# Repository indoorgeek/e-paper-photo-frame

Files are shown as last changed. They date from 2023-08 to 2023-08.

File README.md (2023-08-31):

# E-Paper Photo Frame
 <br/>
Someone has rightly said that "Memories are special moments that tell our story!". I wanted to build something which can bring back the old memories from my favorite places. I had recently got my hands on an e-paper display and such displays mimic the appearance of ink on a good old paper. Perfect! I made a photo frame using a PCB showing my favorite places on a map. Touching any one of the location pads displays an image from that place on the e-paper display.
# The Plan

The brains of the project is an ESP32 microcontroller. I chose this microcontroller mainly for its touch sensing capability on 10 GPIO pins.

The plan is to display a few of my favorite places on a map on the PCB's silkscreen layer. The copper touchpads would then be placed pointing at the locations. The PCB will have a cutout in the middle for the e-paper display i.e. the PCB itself will be a part of the frame. PCB will have a black solder mask along with an ENIG finish. White silkscreen on a black background and gold-plated touchpads. Sweet!

Next, I have to select my favorite images from each location, prepare them for the e-paper display in bitmap (BMP) format, and store them on an SD card.

The next step is to write a code that detects touch and displays an image from that place.

Finally, the last step is to design and 3D print a body to hold all the electronics.
# PCB Design
<p float="center">
  
   
</p>
The first step is to create a silkscreen layer showing the layout of the maps. I wanted only the roads to be visible on the map. For that, I used [this](https://mapstyle.withgoogle.com/) amazing tool by Google Maps. It allows us to edit a lot of things visible on the map. I removed all the buildings and labels and set the color of the road to black and the rest of everything to white. I then grabbed a screenshot and converted the image into PNG showing only the roads and some other stuff that I wanted to be on the silkscreen layer. Finally, after converting the PNG to DXF (which shows just the outline), I imported it onto the silkscreen layer. Pretty sure that there's an efficient way of doing it.

Next, I designed the copper touchpads (as a PCB footprint) to look like the map 'location' symbol. I then placed the pads on the front copper layer at appropriate locations. When it comes to capacitive touchpads, there are few rules which you need to follow. You can read a complete guide on touchpad design [here](https://github.com/ESP32DE/esp-iot-solution-1/blob/master/documents/touch_pad_solution/touch_sensor_design_en.md). That's a lot but this is the minimum I followed and it worked:
- Trace length should not exceed 300mm
- Trace width < 0.18mm (7 mil)
- The angle between two connecting trace segments should not be less than 90 degrees
- No ground plane directly behind (i.e. on bottom layer) or beside the pad. The guide tells us to add a 'hatched' ground plane but that would have affected the appearance. Anyway, it worked for me.
- No ground plane besides the traces
- Pads and traces on the separate layers
- Make sure that there is no ground pour under ESP32's antennae.

I finally exported the gerber files and sent them to [JLCPCB](https://jlcpcb.com/) for fabrication.

# Time for Code
## Preparing Images
Refer this amazing [guide](https://learn.adafruit.com/preparing-graphics-for-e-ink-displays/convert-with-photoshop) by Adafruit to convert images into proper readable format using Photoshop.<br/>
Before you copy your images on the SD card, make sure that the image file names are in UPPERCASE. For example, PIC1.BMP.
## Code
The code basically performs the following functions:
- It checks if a touch is detected using touch interrupts and displays an image associated with that touchpad
- If the time elapsed is > 1hr, it displays a joke/quote from the internet (for fun!)<br/>

I am pulling jokes from [JokeAPI](https://official-joke-api.appspot.com/) and quotes from [Quotable](https://github.com/lukePeavey/quotable). The data is received in JSON format which is deserialized to get the required jokes/quotes.

I have used the following libraries in the code:
- 4.3-inch [EPD](https://github.com/Arduinolibrary/DFRobot_E_paper) library by DFRobots
- [ArduinoJson](https://github.com/bblanchon/ArduinoJson) by bblanchon

All other libraries should be already there by default when you install the boards.

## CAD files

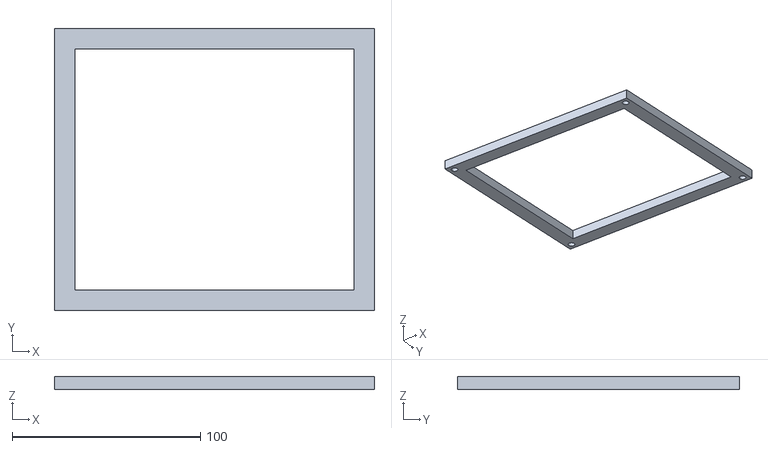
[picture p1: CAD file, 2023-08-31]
3D/Front+Face.stl
170.0 x 150.0 x 7.00

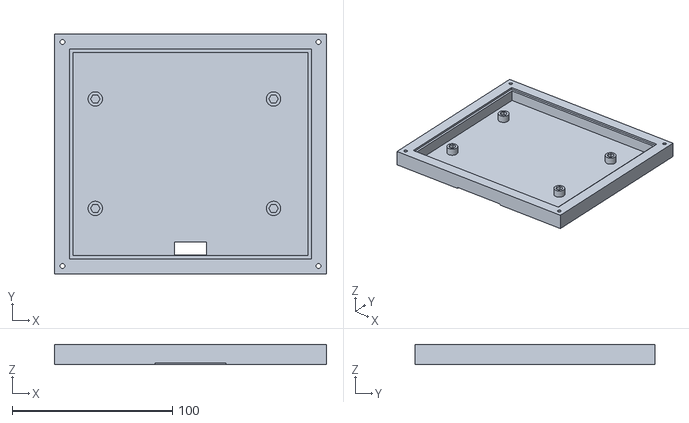
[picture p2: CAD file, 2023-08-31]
3D/Body.stl
170.0 x 150.0 x 12.6

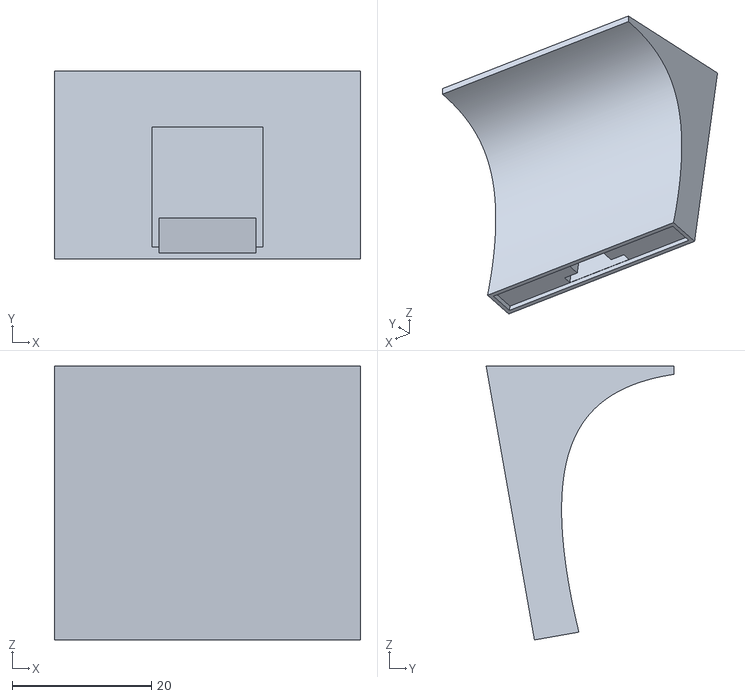
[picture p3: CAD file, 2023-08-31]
3D/Stand_new.stl
44.0 x 27.0 x 39.4

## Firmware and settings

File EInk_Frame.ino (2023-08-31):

#include <epd.h>
#define Threshold 40
#include <WiFi.h>
#include <HTTPClient.h>
#include <ArduinoJson.h>
#include <ESPmDNS.h>
#include <WiFiUdp.h>
#include <ArduinoOTA.h>

const char* ssid = "SSID";          //Enter your WiFi SSID
const char* password = "PASSWORD";  //Enter your WiFi Password
unsigned long previousMillis = 0;
const long interval = 3600000;
int touchPad;
bool touchDetected = false;
int flag = 0;
int i = 0;

HTTPClient http;
                      
void setup() {
  Serial.begin(115200);
  delay(1000); // give me time to bring up serial monitor
  //Serial.println("Booting");
//  WiFi.mode(WIFI_STA);
  WiFi.begin(ssid, password);
  delay(1000);
  
  touchAttachInterrupt(T0, gotTouch0, Threshold);
  touchAttachInterrupt(T3, gotTouch3, Threshold);
  touchAttachInterrupt(T4, gotTouch4, Threshold);
  touchAttachInterrupt(T5, gotTouch5, Threshold);
  touchAttachInterrupt(T6, gotTouch6, Threshold);
  touchAttachInterrupt(T7, gotTouch7, Threshold);
  touchAttachInterrupt(T8, gotTouch8, Threshold);

  epd_init();
  epd_wakeup();
  epd_clear();
  epd_set_memory(MEM_TF);
}

void loop(){
  unsigned long currentMillis = millis();
  if(touchDetected){ //Check continuously if any touch is detected
    epd_wakeup();
    epd_clear();
    switch(touchPad){
      case 0  : epd_disp_bitmap("PIC1.BMP", 0, 0); break;
      case 3  : epd_disp_bitmap("PIC2.BMP", 0, 0); break;
      case 4  : epd_disp_bitmap("PIC3.BMP", 0, 0); break;
      case 5  : epd_disp_bitmap("PIC4.BMP", 0, 0); break;
      case 6  : epd_disp_bitmap("PIC5.BMP", 0, 0); break;
      case 7  : epd_disp_bitmap("PIC6.BMP", 0, 0); break;
      case 8  : epd_disp_bitmap("PIC7.BMP", 0, 0); break;
      default : break;
    }
    epd_udpate();
    touchDetected = false;
  }

  //Get a random joke from JokeAPI after every 1 hour if WiFi is connected
  if (currentMillis - previousMillis >= interval && WiFi.status() == WL_CONNECTED && flag == 0){
    epd_wakeup();
    epd_clear();
    http.begin("https://official-joke-api.appspot.com/random_joke");
    http.GET();
    DynamicJsonBuffer jb;
    JsonObject& obj = jb.parseObject(http.getStream());
    if (!obj.success()){
      Serial.println("parseObject() failed");
      return;
    }
    String joke = obj["setup"];
    String punch = obj["punchline"];
    if(joke.length() > 60){
      String joke1 = joke.substring(0, 60);
      String joke2 = joke.substring(60);
      const void * joke1_c = joke1.c_str();
      const void * joke2_c = joke2.c_str();
      epd_set_color(BLACK, WHITE);
      epd_set_en_font(ASCII32);
      epd_disp_string(joke1_c, 0, 220);
      epd_disp_string(joke2_c, 0, 250);
    }
    else{
      const void * joke_c = joke.c_str();
      epd_set_color(BLACK, WHITE);
      epd_set_en_font(ASCII32);
      epd_disp_string(joke_c, 0, 250);
    }
    if(punch.length() > 60){
      String punch1 = punch.substring(0, 60);
      String punch2 = punch.substring(60);
      const void * punch1_c = punch1.c_str();
      const void * punch2_c = punch2.c_str();
      epd_set_en_font(ASCII32);
      epd_disp_string(punch1_c, 0, 300);
      epd_disp_string(punch2_c, 0, 330);
    }
    else{
      const void * punch_c = punch.c_str();
      epd_set_color(DARK_GRAY, WHITE);
      epd_set_en_font(ASCII32);
      epd_disp_string(punch_c, 0, 330);
    }
    previousMillis = currentMillis;
    epd_udpate();
    flag = 1; //set flag to get quote after next 1 hour
  }

  //Get a random quote from Quotable after every one hour if WiFi is connected
  if (currentMillis - previousMillis >= interval && WiFi.status() == WL_CONNECTED && flag == 1){
    epd_wakeup();
    epd_clear();
    http.begin("https://api.quotable.io/random?maxLength=110");
    http.GET();
    DynamicJsonBuffer jb;
    JsonObject& obj = jb.parseObject(http.getStream());
    if (!obj.success()){
      Serial.println("parseObject() failed");
      return;
    }
    String quote = obj["content"];
    
    if(quote.length() > 60){
      String quote1 = quote.substring(0, 60);
      String quote2 = quote.substring(60);
      const void * quote1_c = quote1.c_str();
      const void * quote2_c = quote2.c_str();
      epd_set_color(BLACK, WHITE);
      epd_set_en_font(ASCII32);
      epd_disp_string(quote1_c, 0, 220);
      epd_disp_string(quote2_c, 0, 250);
    }
    else{
      const void * quote_c = quote.c_str();
      epd_set_color(BLACK, WHITE);
      epd_set_en_font(ASCII32);
      epd_disp_string(quote_c, 0, 250);
    }
    previousMillis = currentMillis;
    epd_udpate();
    flag = 0; //reset flag to get joke after next 1 hour
  }
  //ArduinoOTA.handle();
}

void gotTouch0(){
 touchDetected = true;
 touchPad = 0;
 delay(500);
}

void gotTouch3(){
 touchDetected = true;
 touchPad = 3;
 delay(500);
}

void gotTouch4(){
 touchDetected = true;
 touchPad = 4;
 delay(500);
}

void gotTouch5(){
 touchDetected = true;
 touchPad = 5;
 delay(500);
}

void gotTouch6(){
 touchDetected = true;
 touchPad = 6;
 delay(500);
}

void gotTouch7(){
 touchDetected = true;
 touchPad = 7;
 delay(500);
}

void gotTouch8(){
 touchDetected = true;
 touchPad = 8;
 delay(500);
}
